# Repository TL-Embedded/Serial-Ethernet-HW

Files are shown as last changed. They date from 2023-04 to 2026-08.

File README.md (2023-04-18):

# Serial-Ethernet-HW

This is an Ethernet to Serial adaptor.
See [Serial-Ethernet-FW](https://github.com/TL-Embedded/Serial-Ethernet-FW) for the firmware project.

The hardware is done using KiCad, and uses my component library found here: [KiCadLib](https://github.com/Lambosaurus/KicadLib)

The processor is a STM32G061.

# Ethernet
The ethernet is managed by a SPI attached W5500. The ethernet is capable of 10/100 speeds.

# Serial
The serial is a TTL level serial targeted at certain test equipment. Series resistance is used to tolerate both 3V3 and 5V0 devices.

**This is not compatible with RS232 level serial**

# Power
The device is powered from 5V. This can be supplied via:
 * USB Connector
 * Debug connector
 * DB9 pin 1 (omit L2 if this is not desired)

# Debugging
The debugging connector is a TC2050 compatible footprint. See the [SWD-UART_CTX-10](https://github.com/TL-Embedded/SWD-UART-CTX-10) project for the adaptor board.

This can be used to:
 * Connect to the STM32 via STLINK
 * Supply 5V
 * Connect a UART

The debugging connector has no input/output protection - so take care not to supply power or UART when the DB9 is connected.

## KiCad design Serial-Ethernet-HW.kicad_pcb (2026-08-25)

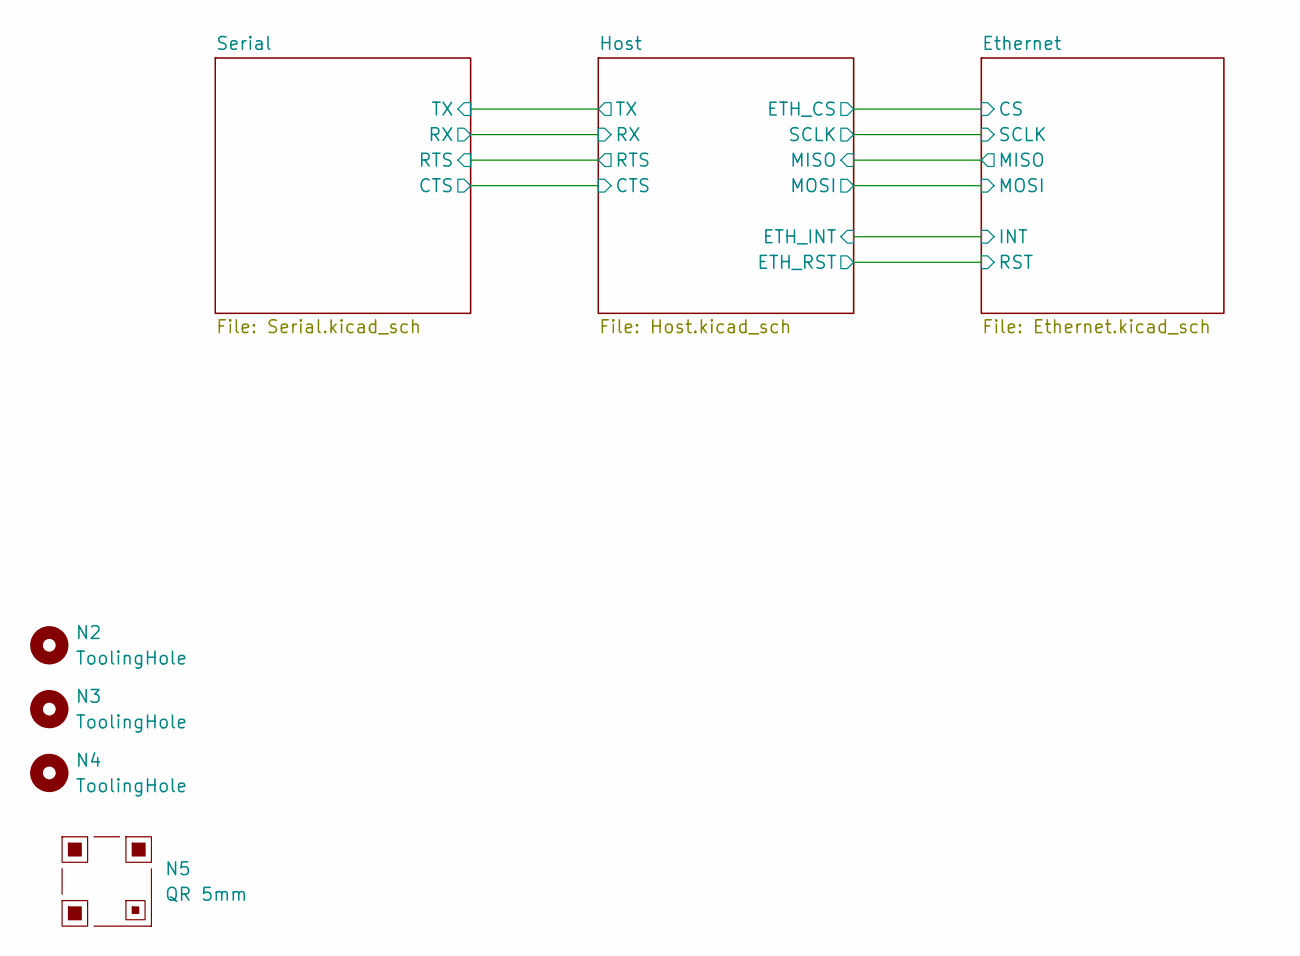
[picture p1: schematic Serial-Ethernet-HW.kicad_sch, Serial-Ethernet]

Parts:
N2, N3, N4: ToolingHole; ToolingHole_1mm
N5: QR 5mm; QR_5mm_JLC

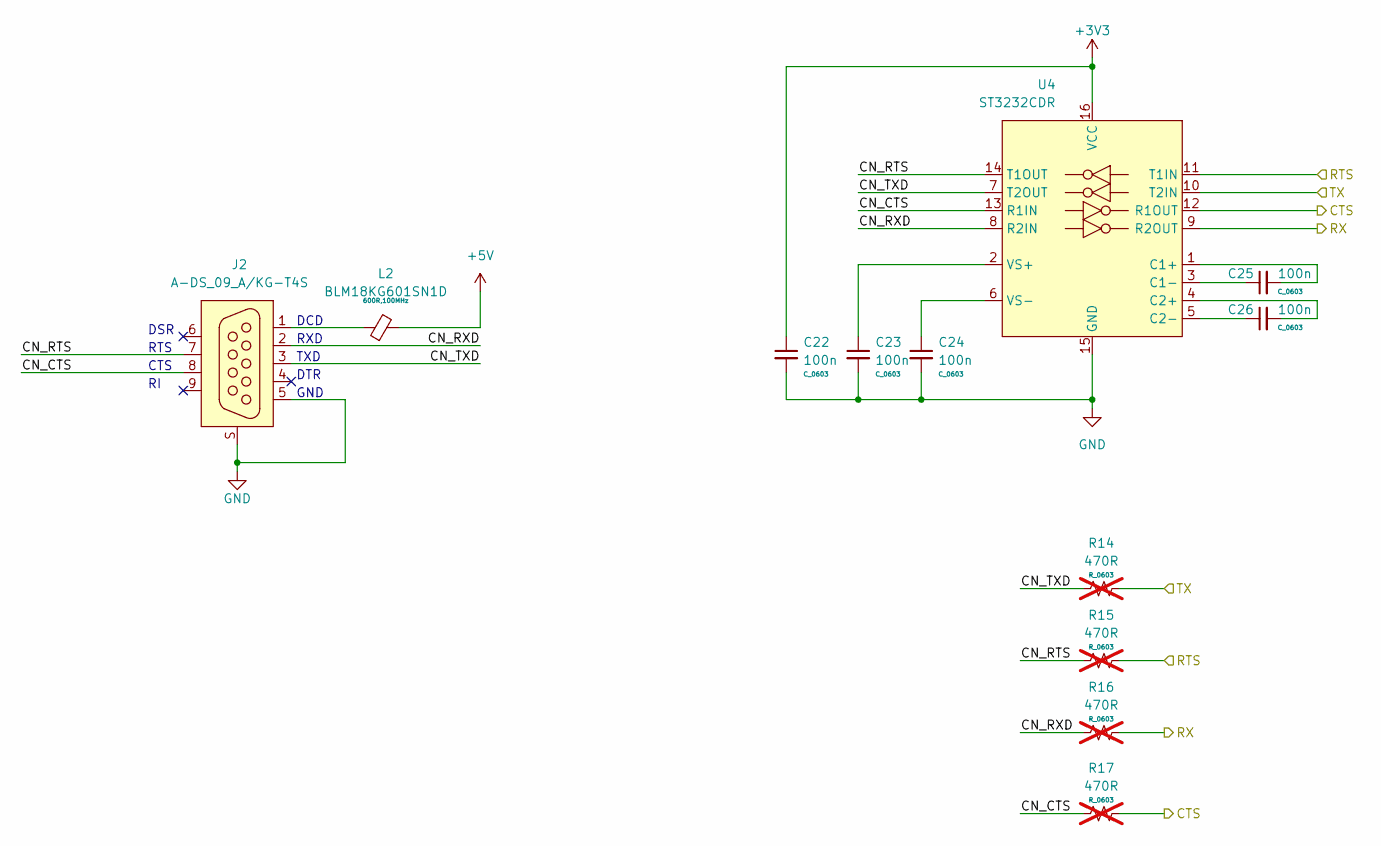
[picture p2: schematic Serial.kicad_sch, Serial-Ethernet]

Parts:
C22, C23, C24, C25, C26: 100n; C_0603
J2: A-DS_09_A/KG-T4S; DSUB09_Male_Horizontal
L2: BLM18KG601SN1D; FB_0603
R14, R15, R16, R17: 470R; R_0603; not fitted
U4: ST3232CDR; SOIC_16

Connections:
+3V3: C22.1, U4.16 (VCC); also elsewhere on the board
+5V: L2.2; also elsewhere on the board
/Host/CTS: R17.2, U4.12 (R1OUT); also elsewhere on the board
/Host/RTS: R15.2, U4.11 (T1IN); also elsewhere on the board
/Host/UART_RX: R16.2, U4.9 (R2OUT); also elsewhere on the board
/Host/UART_TX: R14.2, U4.10 (T2IN); also elsewhere on the board
/Serial/CN_CTS: J2.8, R17.1, U4.13 (R1IN)
/Serial/CN_RTS: J2.7, R15.1, U4.14 (T1OUT)
/Serial/CN_RXD: J2.2, R16.1, U4.8 (R2IN)
/Serial/CN_TXD: J2.3, R14.1, U4.7 (T2OUT)
GND: C22.2, C23.2, C24.2, J2.5, J2.S, U4.15 (GND); also elsewhere on the board
unnamed: J2.1, L2.1
unnamed: C25.2, U4.1 (C1+)
unnamed: C25.1, U4.3 (C1-)
unnamed: C26.2, U4.4 (C2+)
unnamed: C26.1, U4.5 (C2-)
unnamed: C23.1, U4.2 (VS+)
unnamed: C24.1, U4.6 (VS-)

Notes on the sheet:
GND
TXD
CTS
RXD
DTR
RTS
DSR
DCD

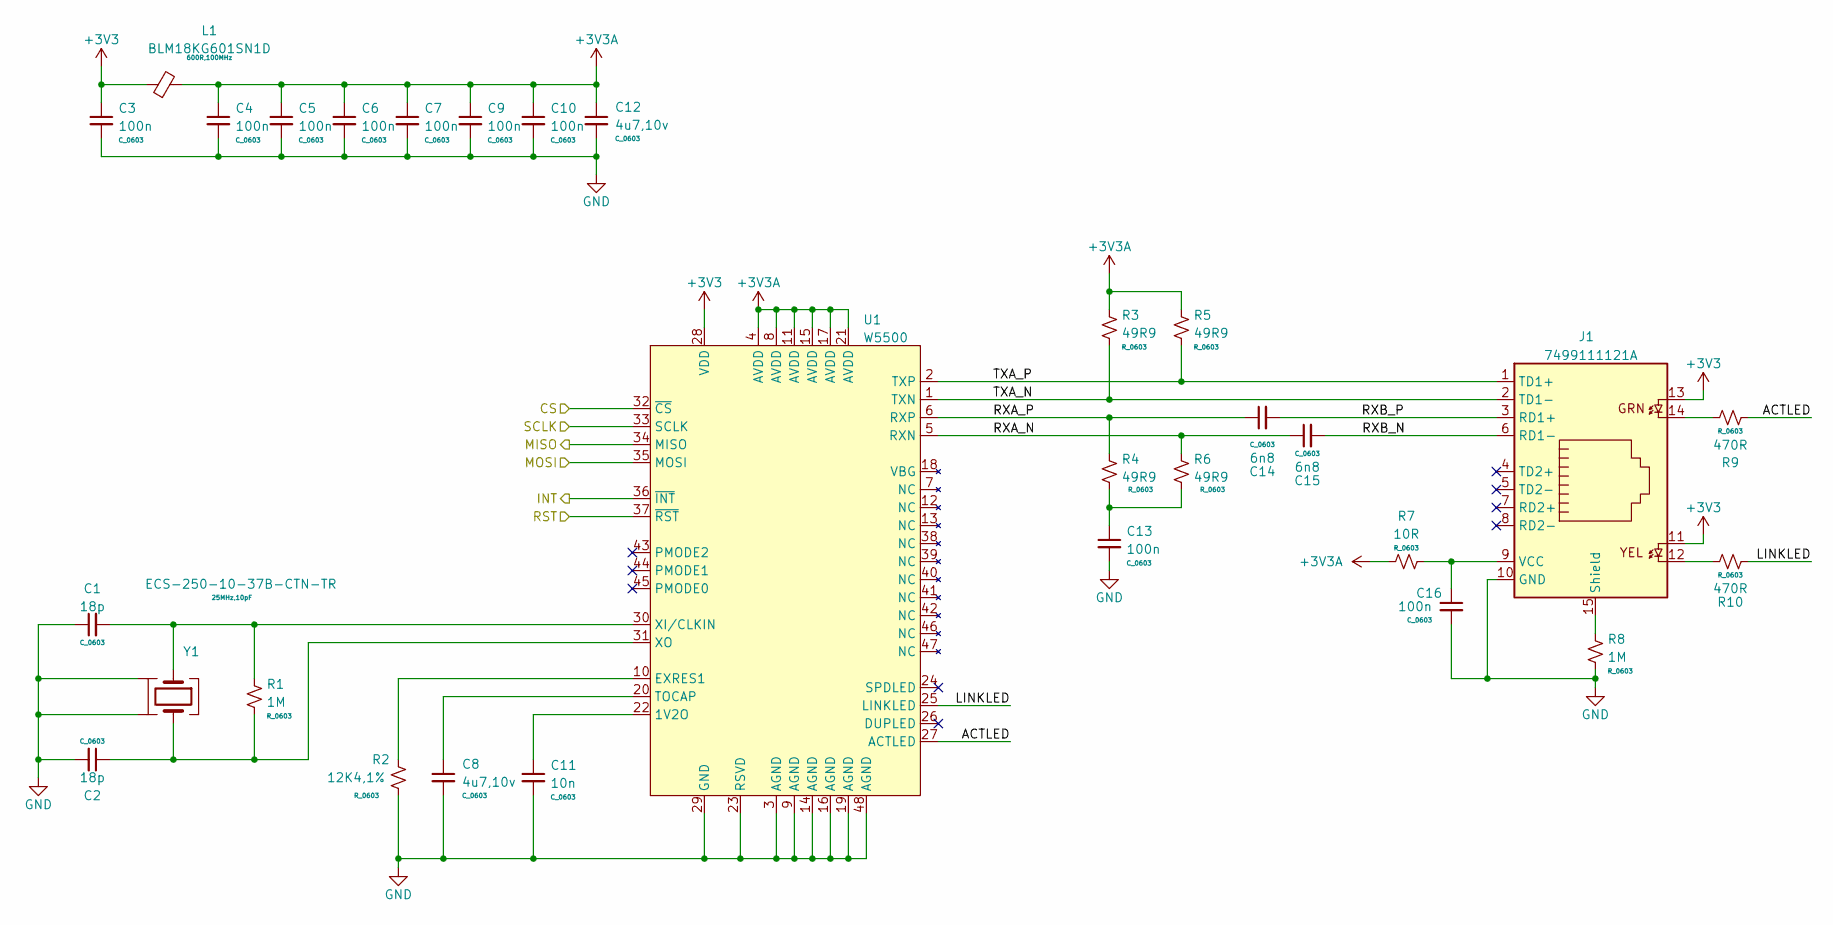
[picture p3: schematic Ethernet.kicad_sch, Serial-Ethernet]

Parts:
C1, C2: 18p; C_0603
C3, C4, C5, C6, C7, C9, C10, C13, C16: 100n; C_0603
C8, C12: 4u7,10v; C_0603
C11: 10n; C_0603
C14, C15: 6n8; C_0603
J1: 7499111121A; 7499210121A
L1: BLM18KG601SN1D; FB_0603
R1, R8: 1M; R_0603
R2: 12K4,1%; R_0603
R3, R4, R5, R6: 49R9; R_0603
R7: 10R; R_0603
R9, R10: 470R; R_0603
U1: W5500; LQFP48_05_7x7
Y1: ECS-250-10-37B-CTN-TR; Crystal_SMD4_2.0x1.6

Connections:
+3V3: C3.1, J1.11, J1.13, L1.1, U1.28 (VDD); also elsewhere on the board
+3V3A: C4.1, C5.1, C6.1, C7.1, C9.1, C10.1, C12.1, L1.2, R3.1, R5.1, R7.1, U1.4 (AVDD), U1.8 (AVDD), U1.11 (AVDD), U1.15 (AVDD), U1.17 (AVDD), U1.21 (AVDD)
/Ethernet/ACTLED: R9.1, U1.27 (ACTLED)
/Ethernet/CS: U1.32 (~CS); also elsewhere on the board
/Ethernet/INT: U1.36 (~INT); also elsewhere on the board
/Ethernet/LINKLED: R10.2, U1.25 (LINKLED)
/Ethernet/MISO: U1.34 (MISO); also elsewhere on the board
/Ethernet/MOSI: U1.35 (MOSI); also elsewhere on the board
/Ethernet/RST: U1.37 (~RST); also elsewhere on the board
/Ethernet/RXA_N: C15.1, R6.1, U1.5 (RXN)
/Ethernet/RXA_P: C14.1, R4.1, U1.6 (RXP)
/Ethernet/RXB_N: C15.2, J1.6 (RD1-)
/Ethernet/RXB_P: C14.2, J1.3 (RD1+)
/Ethernet/SCLK: U1.33 (SCLK); also elsewhere on the board
/Ethernet/TXA_N: J1.2 (TD1-), R3.2, U1.1 (TXN)
/Ethernet/TXA_P: J1.1 (TD1+), R5.2, U1.2 (TXP)
GND: C1.1, C2.2, C3.2, C4.2, C5.2, C6.2, C7.2, C8.2, C9.2, C10.2, C11.2, C12.2, C13.2, C16.2, J1.10 (GND), R2.2, R8.2, U1.3 (AGND), U1.9 (AGND), U1.14 (AGND), U1.16 (AGND), U1.19 (AGND), U1.23 (RSVD), U1.29 (GND), U1.48 (AGND), Y1.2, Y1.4; also elsewhere on the board
unnamed: C13.1, R4.2, R6.2
unnamed: J1.12, R10.1
unnamed: J1.14, R9.2
unnamed: J1.15 (Shield), R8.1
unnamed: C16.1, J1.9 (VCC), R7.2
unnamed: C11.1, U1.22 (1V2O)
unnamed: R2.1, U1.10 (EXRES1)
unnamed: C8.1, U1.20 (TOCAP)
unnamed: C1.2, R1.1, U1.30 (XI/CLKIN), Y1.1
unnamed: C2.1, R1.2, U1.31 (XO), Y1.3

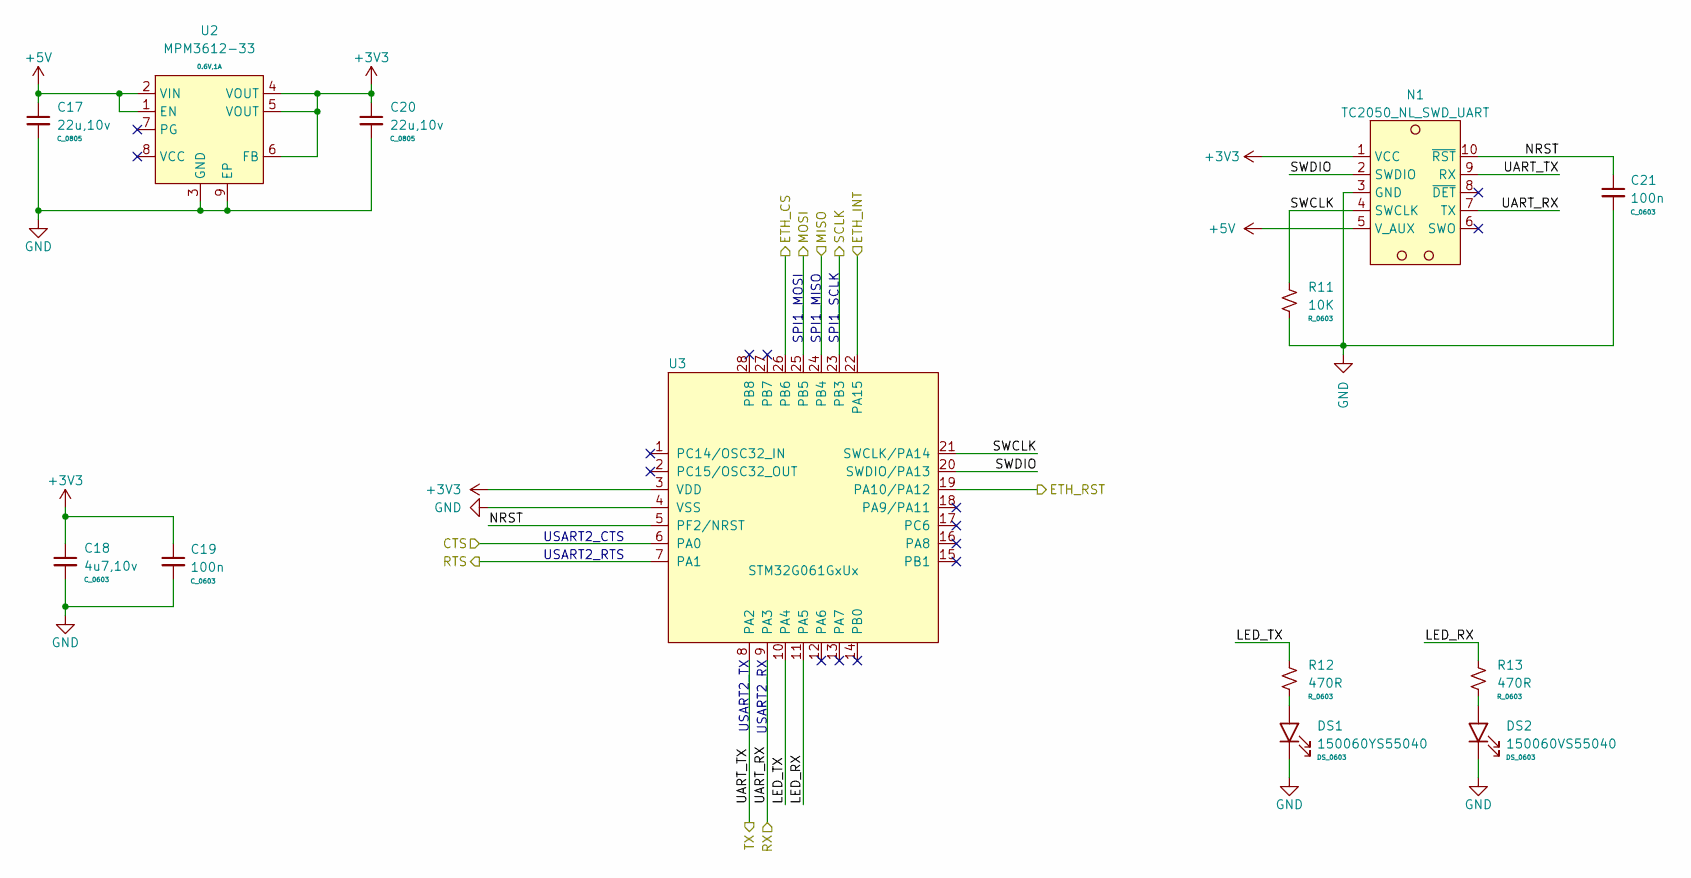
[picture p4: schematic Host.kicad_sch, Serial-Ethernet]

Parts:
C17, C20: 22u,10v; C_0805
C18: 4u7,10v; C_0603
C19, C21: 100n; C_0603
DS1: 150060YS55040; DS_0603
DS2: 150060VS55040; DS_0603
N1: TC2050_NL_SWD_UART; TagConnect_TC2050_NL
R11: 10K; R_0603
R12, R13: 470R; R_0603
U2: MPM3612-33; LGA8_3x3_EP_MPM
U3: STM32G061GxUx; QFN28_05_4x4

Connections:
+3V3: C18.1, C19.1, C20.1, N1.1 (VCC), U2.4 (VOUT), U2.5 (VOUT), U2.6 (FB), U3.3 (VDD); also elsewhere on the board
+5V: C17.1, N1.5 (V_AUX), U2.1 (EN), U2.2 (VIN); also elsewhere on the board
/Ethernet/CS: U3.26 (PB6); also elsewhere on the board
/Ethernet/INT: U3.22 (PA15); also elsewhere on the board
/Ethernet/MISO: U3.24 (PB4); also elsewhere on the board
/Ethernet/MOSI: U3.25 (PB5); also elsewhere on the board
/Ethernet/RST: U3.19 (PA10/PA12); also elsewhere on the board
/Ethernet/SCLK: U3.23 (PB3); also elsewhere on the board
/Host/CTS: U3.6 (PA0); also elsewhere on the board
/Host/LED_RX: R13.1, U3.11 (PA5)
/Host/LED_TX: R12.1, U3.10 (PA4)
/Host/NRST: C21.1, N1.10 (~RST), U3.5 (PF2/NRST)
/Host/RTS: U3.7 (PA1); also elsewhere on the board
/Host/SWCLK: N1.4 (SWCLK), R11.1, U3.21 (SWCLK/PA14)
/Host/SWDIO: N1.2 (SWDIO), U3.20 (SWDIO/PA13)
/Host/UART_RX: N1.7 (TX), U3.9 (PA3); also elsewhere on the board
/Host/UART_TX: N1.9 (RX), U3.8 (PA2); also elsewhere on the board
GND: C17.2, C18.2, C19.2, C20.2, C21.2, DS1.1 (K), DS2.1 (K), N1.3 (GND), R11.2, U2.3 (GND), U2.9 (EP), U3.4 (VSS); also elsewhere on the board
unnamed: DS1.2 (A), R12.2
unnamed: DS2.2 (A), R13.2

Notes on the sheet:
SPI1_SCLK
SPI1_MOSI
SPI1_MISO
USART2_RTS
USART2_RX
USART2_CTS
USART2_TX

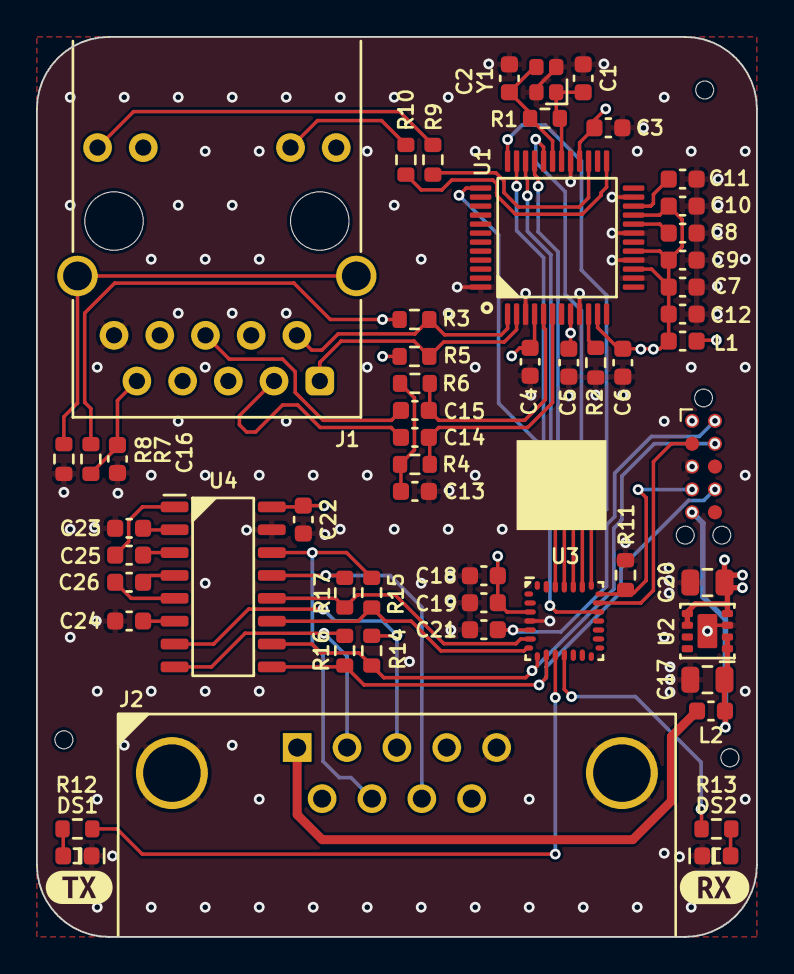
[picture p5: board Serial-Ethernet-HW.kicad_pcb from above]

Board: 4 copper layers, 40.0 x 50.0 mm, 61 parts (0 on the bottom side), 50 nets.

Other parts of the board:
kibuzzard-6A8D4FDF: G***; kibuzzard-6A8D4FDF
kibuzzard-6A8D4FE5: G***; kibuzzard-6A8D4FE5

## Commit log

2023-02-09 Version 1.0
    [Ethernet.kicad_sch, Host.kicad_sch, Serial-Ethernet-HW.kicad_pcb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]
2023-04-18 Reference kicad lib in readme
2025-09-13 Rebuild using new output scripts
    [Ethernet.kicad_sch, Host.kicad_sch, Serial-Ethernet-HW.kicad_pcb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]
2026-08-23 Update to kicad 10
    [Ethernet.kicad_sch, Host.kicad_sch, Serial-Ethernet-HW.kicad_pcb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]
2026-08-23 Add in RS232
    [Ethernet.kicad_sch, Host.kicad_sch, Serial-Ethernet-HW.kicad_sch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]
2026-08-25 PCB Layout
    [Ethernet.kicad_sch, Host.kicad_sch, Serial-Ethernet-HW.kicad_pcb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]
2026-08-25 Add stitching vias
    [Serial-Ethernet-HW.kicad_pcb]
